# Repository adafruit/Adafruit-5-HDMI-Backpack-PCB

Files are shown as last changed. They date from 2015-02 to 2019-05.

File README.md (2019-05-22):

## Adafruit 5" HDMI Backpack PCB
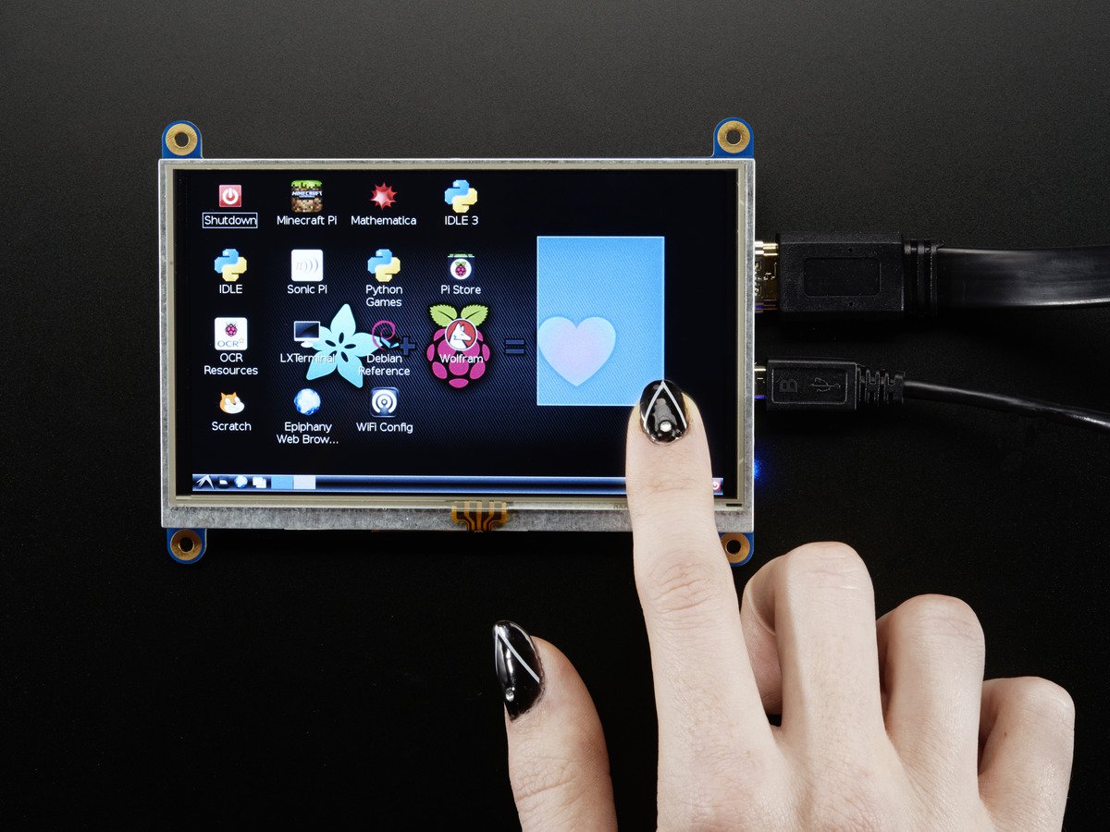
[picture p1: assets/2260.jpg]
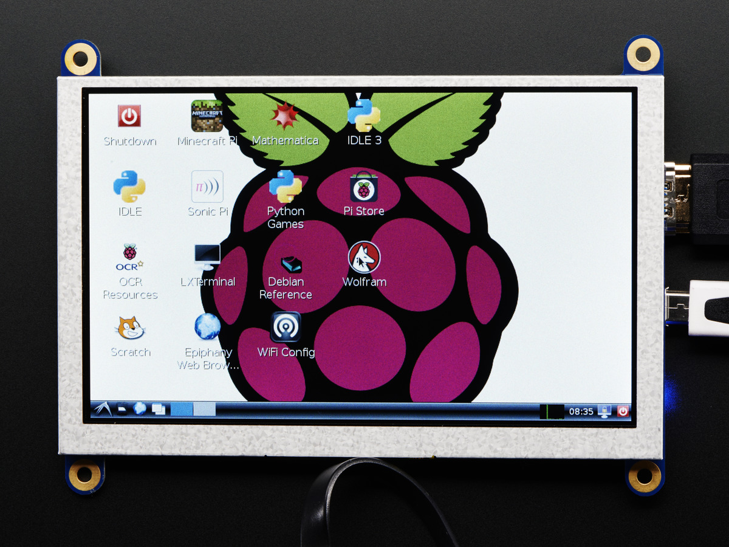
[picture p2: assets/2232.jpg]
&nbsp; <br />
Click to purchase from the Adafruit Shop:
- [HDMI 5" 800x480 Display Backpack - With Resistive Touchscreen](https://www.adafruit.com/product/2260)
- [HDMI 5" Display Backpack - Without Touch](https://www.adafruit.com/product/2232)

Its a mini panel-mountable HDMI monitor with a built-in resistive touchscreen! So small and simple, you can use this display with any computer that has HDMI output, and the shape makes it easy to attach to a case or rail. This backpack features the TFP401 for decoding video, and includes the attached display so its plug-n-play.

The TFP401 is a beefy DVI/HDMI decoder from TI. It can take unencrypted video and pipe out the raw 24-bit color pixel data - HDCP not supported! The 5" display is 800x480 resolution, which is just enough to run most software, but still small enough that it can be used in portable or embedded projects without the bulk.

This is the PCB for the Adafruit 5" TFT HDMI backpacks. The format is EagleCAD schematic and board layout

For more details, check out the product pages at
- https://www.adafruit.com/product/2260
- https://www.adafruit.com/product/2232

### License

Adafruit invests time and resources providing this open source design, please support Adafruit and open-source hardware by purchasing products from [Adafruit](https://www.adafruit.com)!

All text above must be included in any redistribution

Designed by Limor Fried/Ladyada for Adafruit Industries.
Creative Commons Attribution/Share-Alike, all text above must be included in any redistribution. 
See license.txt for additional information.Adafruit invests time and resources providing this open source design, 
please support Adafruit and open-source hardware by purchasing 
products from Adafruit!

Designed by Adafruit Industries.  
Creative Commons Attribution, Share-Alike license, check license.txt for more information
All text above must be included in any redistribution

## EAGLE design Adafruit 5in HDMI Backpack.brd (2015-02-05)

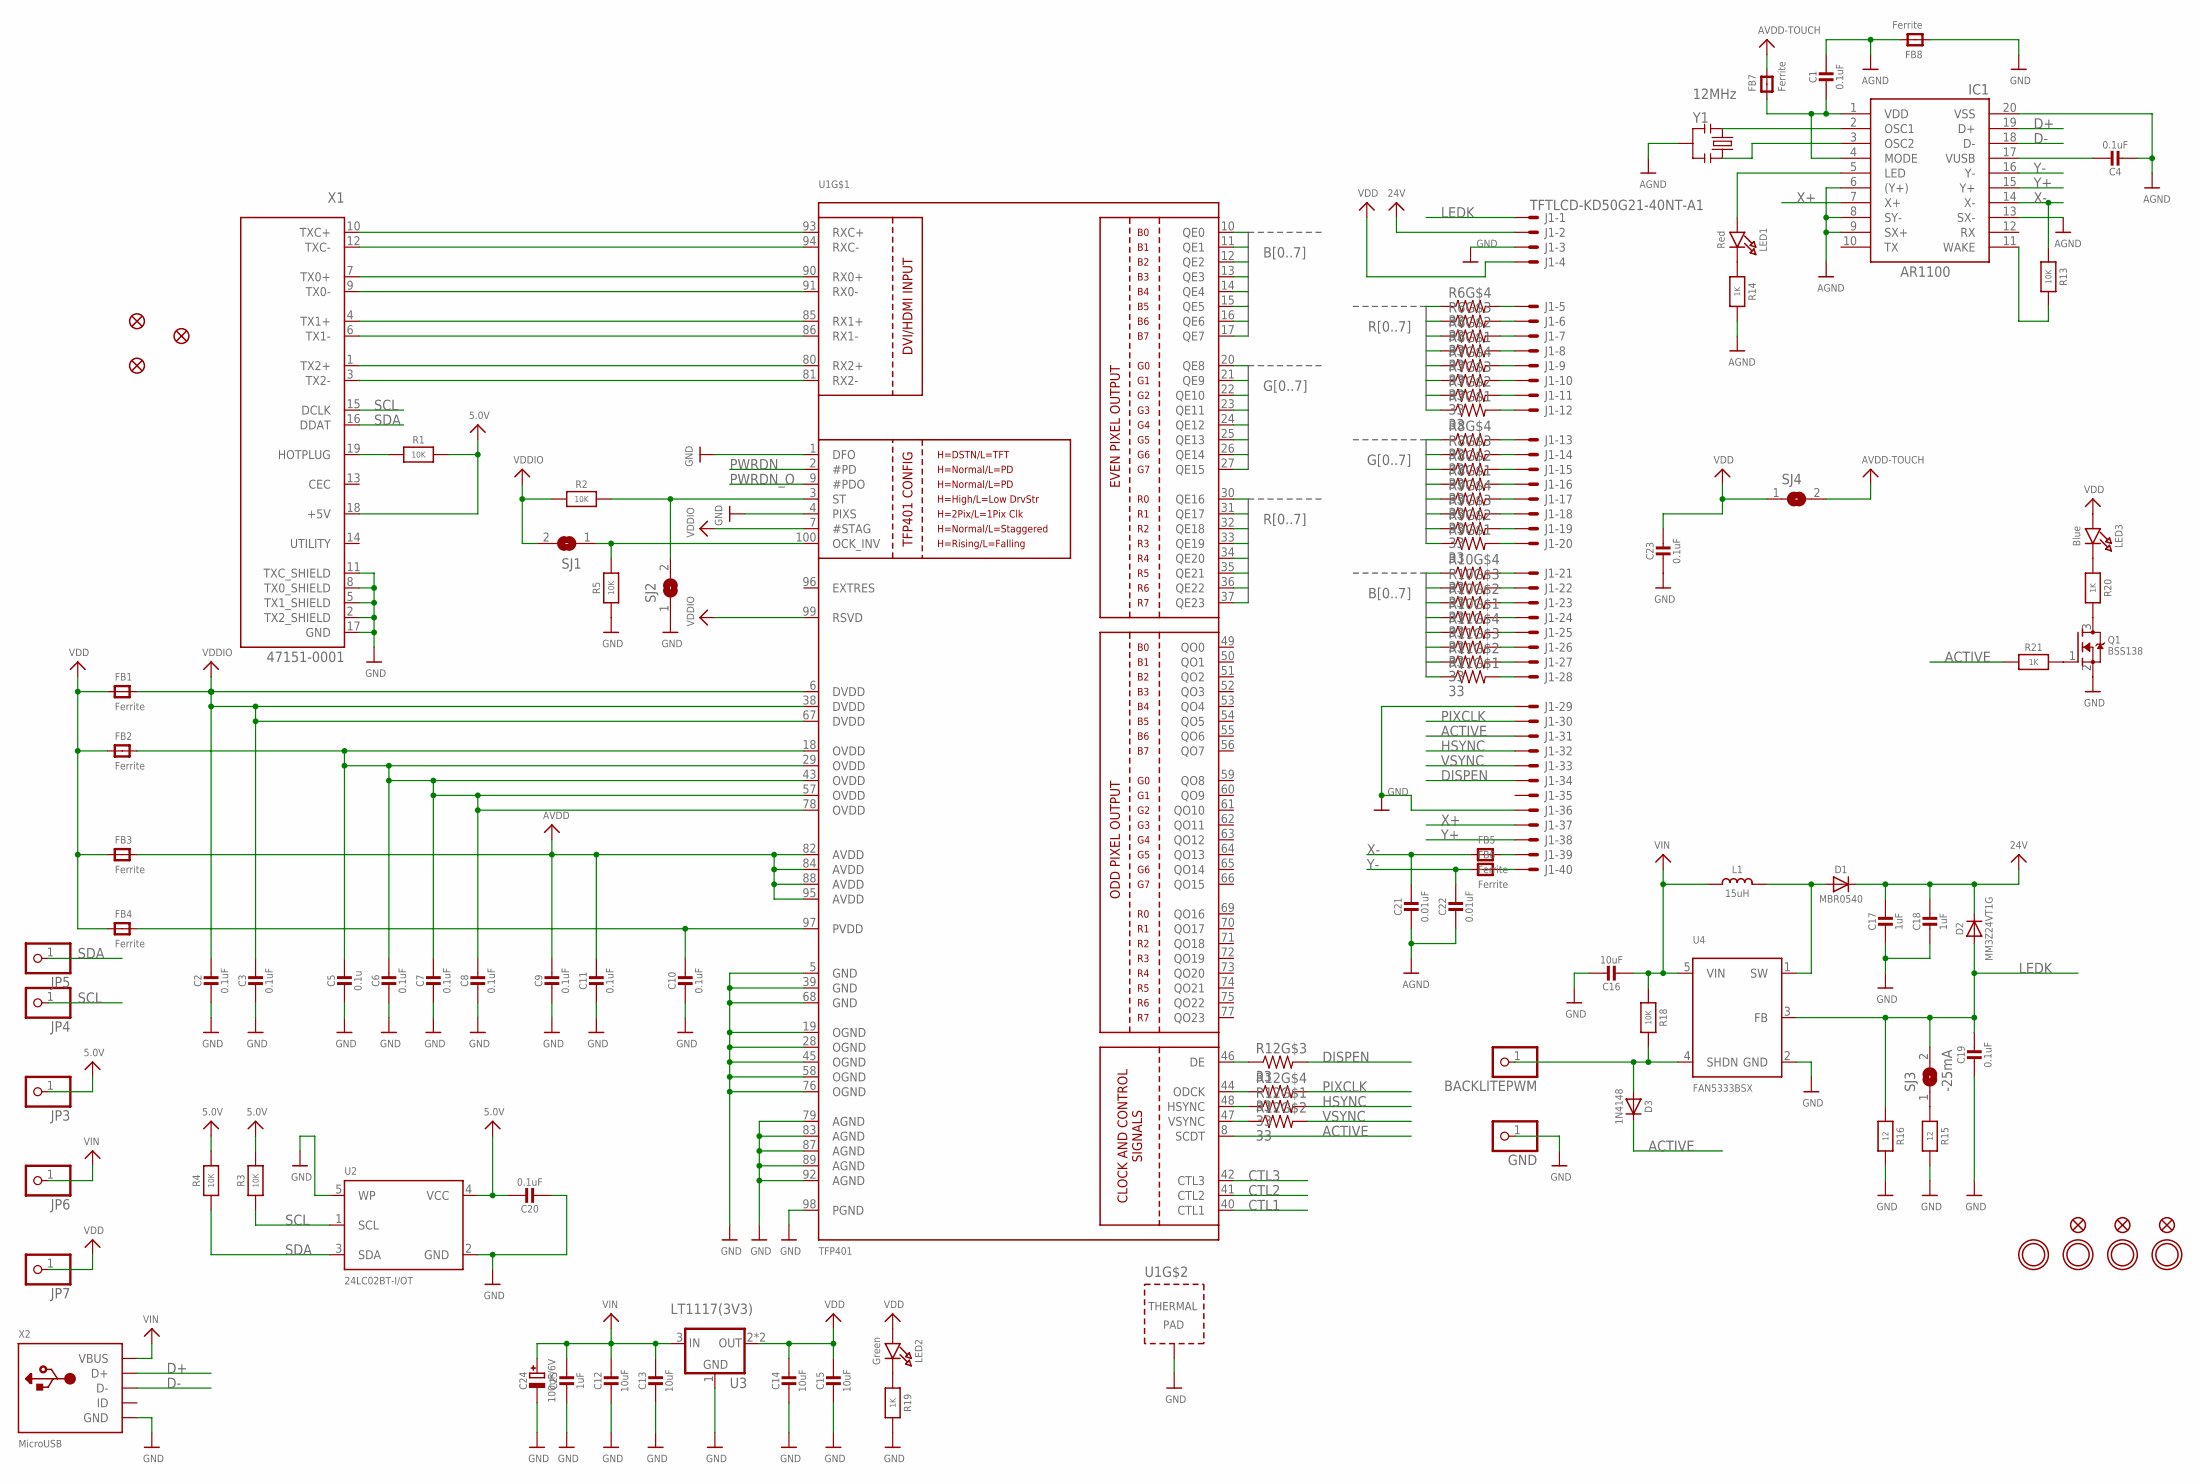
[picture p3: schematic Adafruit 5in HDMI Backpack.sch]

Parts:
BACKLITEPWM: HEADER-1X1-SMD_MASKHELD_2X2MM; 1X01_SMD_MASKHELD_2X2MM
C1, C2, C3, C7, C8, C9, C10, C11, C19, C20, C23: 0.1uF; 0805-NO
C4, C6: 0.1uF; _0805MP
C5: 0.1u; 0805-NO
C12, C13, C14, C15, C16: 10uF; 0805-NO
C17, C18, C25: 1uF; 0805-NO
C21, C22: 0.01uF; 0805-NO
C24: 100uF/6V; PANASONIC_C
D1: MBR0540; SOD-123
D2: MM3Z24VT1G; SMADIODE
D3: 1N4148; SOD-323
FB1, FB2, FB3, FB4, FB5, FB6, FB7, FB8: Ferrite; _0805MP
FID1, FID2, FID3, FID4, FID5, FID6: FIDUCIAL""; FIDUCIAL_1MM
GND: HEADER-1X1-SMD_MASKHELD_2X2MM; 1X01_SMD_MASKHELD_2X2MM
IC1: AR1100; TSSOP20-5.3MMBODY
J1: TFTLCD-KD50G21-40NT-A1
JP3, JP4, JP5, JP6, JP7: HEADER-1X1-SMD_MASKHELD_2X2MM; 1X01_SMD_MASKHELD_2X2MM
L1: 15uH; INDUCTOR_5X5MM_NR5040_NOTHERMALS
LED1: Red; CHIPLED_0805_NOOUTLINE
LED2: Green; CHIPLED_0805_NOOUTLINE
LED3: Blue; CHIPLED_0805_NOOUTLINE
Q1: BSS138; SOT23-WIDE
R1, R3, R4, R13, R18: 10K; 0805-NO
R2, R5: 10K; _0805MP
R6, R7, R8, R9, R10, R11, R12: 33; RESPACK_4X0603
R14, R19, R20, R21: 1K; 0805-NO
R15, R16: 12; 0805-NO
SJ1, SJ2: SOLDERJUMPER; SOLDERJUMPER_ARROW_NOPASTE
SJ3: -25mA; SOLDERJUMPER_CLOSEDWIRE
SJ4: SOLDERJUMPERCLOSED; SOLDERJUMPER_CLOSEDWIRE
U1: TFP401; S-PQFP-G100
U2: 24LC02BT-I/OT; SOT23-5
U3: LT1117(3V3); SOT223-R
U4: FAN5333BSX; SOT23-5
U$31, U$32, U$33, U$34: MOUNTINGHOLE3.0; MOUNTINGHOLE_3.0_PLATED
X1: 47151-0001; HDMI_MOLEX_47151-0001_DIMLAYER
X2: MicroUSB; 4UCONN_20329
Y1: 12MHz; RESONATOR-SMD

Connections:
5.0V: C20.1, JP3.1, R1.2, R3.2, R4.2, U2.4 (VCC), X1.18 (+5V)
24V: C17.1, C18.1, D1.C, D2.C, J1.2 (MS)
ACTIVE: D3.C, J1.31 (MS), R21.1, U1.8 (SCDT)
AGND: C1.1, C4.2, C21.2, C22.2, FB8.2, IC1.6 ((Y+)), IC1.8 (SY-), IC1.9 (SX+), IC1.13 (SX-), IC1.20 (VSS), R14.2, Y1.2
ASD: R12.3 (1), U1.46 (DE)
AVDD: C9.1, C11.1, FB3.2, U1.82 (AVDD), U1.84 (AVDD), U1.88 (AVDD), U1.95 (AVDD)
AVDD2: FB7.2, SJ4.2
B0: R10.4 (1), U1.10 (QE0)
B1: R10.3 (1), U1.11 (QE1)
B2: R10.2 (1), U1.12 (QE2)
B3: R10.1, U1.13 (QE3)
B4: R11.4 (1), U1.14 (QE4)
B5: R11.3 (1), U1.15 (QE5)
B6: R11.2 (1), U1.16 (QE6)
B7: R11.1, U1.17 (QE7)
CTL1: U1.40 (CTL1)
CTL2: U1.41 (CTL2)
CTL3: U1.42 (CTL3)
CVB: R12.2 (1), U1.47 (VSYNC)
D+: IC1.19 (D+), X2.D+
D-: IC1.18 (D-), X2.D-
DISPEN: J1.34 (MS), R12.6 (2)
G0: R8.4 (1), U1.20 (QE8)
G1: R8.3 (1), U1.21 (QE9)
G2: R8.2 (1), U1.22 (QE10)
G3: R8.1, U1.23 (QE11)
G4: R9.4 (1), U1.24 (QE12)
G5: R9.3 (1), U1.25 (QE13)
G6: R9.2 (1), U1.26 (QE14)
G7: R9.1, U1.27 (QE15)
GND: C2.2, C3.2, C5.2, C6.2, C7.2, C8.2, C9.2, C10.2, C11.2, C12.2, C13.2, C14.2, C15.2, C16.1, C17.2, C18.2, C19.2, C20.2, C23.2, C24.-, C25.2, FB8.1, GND.1, J1.3 (MS), J1.29 (MS), J1.36 (MS), Q1.2 (S), R5.1, R15.2, R16.2, R19.2, SJ2.1, U1.1 (DFO), U1.4 (PIXS), U1.5 (GND), U1.19 (OGND), U1.28 (OGND), U1.39 (GND), U1.45 (OGND), U1.58 (OGND), U1.68 (GND), U1.76 (OGND), U1.79 (AGND), U1.83 (AGND), U1.87 (AGND), U1.89 (AGND), U1.92 (AGND), U1.98 (PGND), U1.P$1 (TP), U1.P$2 (TP), U1.P$3 (TP), U1.P$4 (TP), U1.P$5 (TP), U1.P$6 (TP), U1.P$7 (TP), U1.P$8 (TP), U1.P$9 (TP), U1.P$10 (TP), U1.P$11 (TP), U1.P$12 (TP), U1.P$13 (TP), U1.P$14 (TP), U1.P$15 (TP), U1.P$16 (TP), U1.THERMAL (TP), U2.2 (GND), U2.5 (WP), U3.1 (GND), U4.2 (GND), X1.2 (TX2_SHIELD), X1.5 (TX1_SHIELD), X1.8 (TX0_SHIELD), X1.11 (TXC_SHIELD), X1.17 (GND), X1.P$1 (GND), X1.P$2 (GND), X1.P$3 (GND), X1.P$4 (GND), X2.BASE@1 (GND), X2.BASE@2 (GND), X2.GND, X2.SPRT@1 (GND), X2.SPRT@2 (GND), X2.SPRT@3 (GND), X2.SPRT@4 (GND)
HSYNC: J1.32 (MS), R12.8 (2)
LEDK: C19.1, D2.A, J1.1 (MSV), R16.1, SJ3.2, U4.3 (FB)
unnamed: U1.93 (RXC+), X1.10 (TXC+)
unnamed: U1.94 (RXC-), X1.12 (TXC-)
unnamed: U1.90 (RX0+), X1.7 (TX0+)
unnamed: U1.91 (RX0-), X1.9 (TX0-)
unnamed: U1.85 (RX1+), X1.4 (TX1+)
unnamed: U1.86 (RX1-), X1.6 (TX1-)
unnamed: U1.80 (RX2+), X1.1 (TX2+)
unnamed: U1.81 (RX2-), X1.3 (TX2-)
unnamed: R1.1, X1.19 (HOTPLUG)
unnamed: IC1.2 (OSC1), Y1.1
unnamed: IC1.3 (OSC2), Y1.3
unnamed: C4.1, IC1.17 (VUSB)
unnamed: LED2.C, R19.1
unnamed: J1.5 (MS), R6.5 (2)
unnamed: J1.6 (MS), R6.6 (2)
unnamed: J1.7 (MS), R6.7 (2)
unnamed: J1.8 (MS), R6.8 (2)
unnamed: J1.9 (MS), R7.5 (2)
unnamed: J1.10 (MS), R7.6 (2)
unnamed: J1.11 (MS), R7.7 (2)
unnamed: J1.12 (MS), R7.8 (2)
unnamed: J1.13 (MS), R8.5 (2)
unnamed: J1.14 (MS), R8.6 (2)
unnamed: J1.15 (MS), R8.7 (2)
unnamed: J1.16 (MS), R8.8 (2)
unnamed: J1.17 (MS), R9.5 (2)
unnamed: J1.18 (MS), R9.6 (2)
unnamed: J1.19 (MS), R9.7 (2)
unnamed: J1.20 (MS), R9.8 (2)
unnamed: J1.21 (MS), R10.5 (2)
unnamed: J1.22 (MS), R10.6 (2)
unnamed: J1.23 (MS), R10.7 (2)
unnamed: J1.24 (MS), R10.8 (2)
unnamed: J1.25 (MS), R11.5 (2)
unnamed: J1.26 (MS), R11.6 (2)
unnamed: J1.27 (MS), R11.7 (2)
unnamed: C10.1, FB4.2, U1.97 (PVDD)
unnamed: J1.28 (MS), R11.8 (2)
unnamed: IC1.11 (WAKE), R13.2
unnamed: LED1.C, R14.1
unnamed: C5.1, C6.1, C7.1, C8.1, FB2.2, U1.18 (OVDD), U1.29 (OVDD), U1.43 (OVDD), U1.57 (OVDD), U1.78 (OVDD)
unnamed: IC1.5 (LED), LED1.A
unnamed: LED3.C, R20.1
unnamed: Q1.3 (D), R20.2
unnamed: D1.A, L1.P$2 (2), U4.1 (SW)
unnamed: Q1.1 (G), R21.2
unnamed: R15.1, SJ3.1
unnamed: BACKLITEPWM.1, D3.A, R18.2, U4.4 (SHDN)
unnamed: FB5.2, J1.39 (MS)
unnamed: FB6.2, J1.40 (MS)
unnamed: C1.2, FB7.1, IC1.1 (VDD), IC1.4 (MODE)
OCK_INV: R5.2, SJ1.1, U1.100 (OCK_INV)
PIXCLK: J1.30 (MS), R12.5 (2)
PWRDN: U1.2 (#PD)
PWRDN_O: U1.9 (#PDO)
R0: R6.4 (1), U1.30 (QE16)
R1: R6.3 (1), U1.31 (QE17)
R2: R6.2 (1), U1.32 (QE18)
R3: R6.1, U1.33 (QE19)
R4: R7.4 (1), U1.34 (QE20)
R5: R7.3 (1), U1.35 (QE21)
R6: R7.2 (1), U1.36 (QE22)
R7: R7.1, U1.37 (QE23)
SCL: JP4.1, R3.1, U2.1 (SCL), X1.15 (DCLK)
SDA: JP5.1, R4.1, U2.3 (SDA), X1.16 (DDAT)
ST: R2.2, SJ2.2, U1.3 (ST)
VDD: C14.1, C15.1, C23.1, FB1.1, FB2.1, FB3.1, FB4.1, J1.4 (MS), JP7.1, LED2.A, LED3.A, SJ4.1, U3.2 (OUT), U3.4 (OUT)
VDDIO: C2.1, C3.1, FB1.2, R2.1, SJ1.2, U1.6 (DVDD), U1.7 (#STAG), U1.38 (DVDD), U1.67 (DVDD), U1.99 (RSVD)
VIN: C12.1, C13.1, C16.2, C24.+, C25.1, JP6.1, L1.P$1 (1), R18.1, U3.3 (IN), U4.5 (VIN), X2.VBUS
VSYNC: J1.33 (MS), R12.7 (2)
X+: IC1.7 (X+), J1.37 (MS)
X-: C21.1, FB5.1, IC1.14 (X-), R13.1
XCV: R12.1, U1.48 (HSYNC)
Y+: IC1.15 (Y+), J1.38 (MS)
Y-: C22.1, FB6.1, IC1.16 (Y-)
ZXC: R12.4 (1), U1.44 (ODCK)

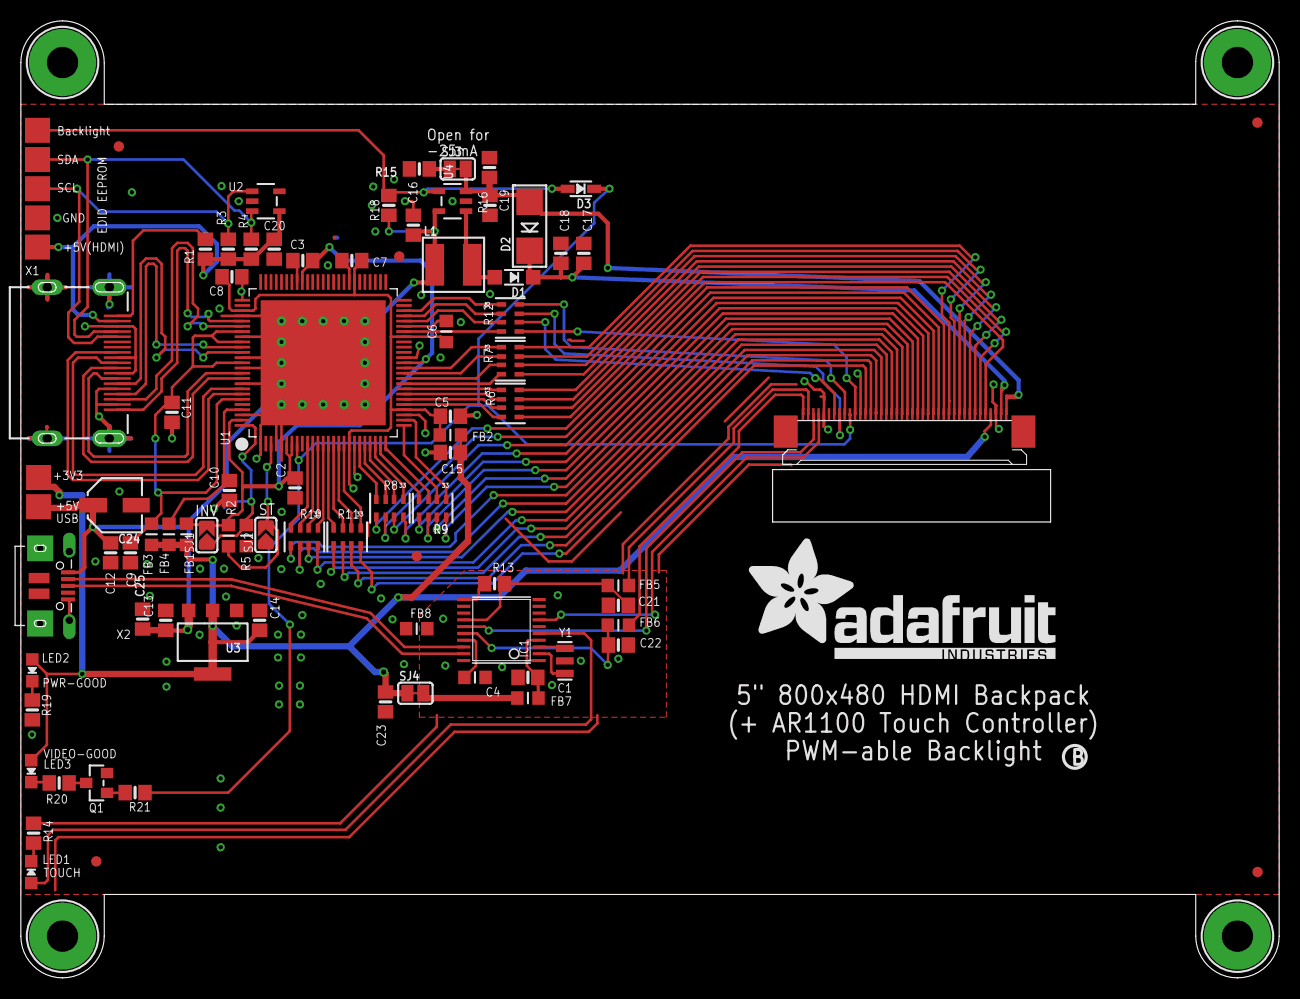
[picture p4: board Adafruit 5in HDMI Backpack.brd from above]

Board: 2 copper layers, 120.7 x 91.8 mm, 93 parts (1 on the bottom side), 104 nets.

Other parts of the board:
U$75: ADAFRUIT_TEXT_30MM
U$76: PCBFEAT-REV-056

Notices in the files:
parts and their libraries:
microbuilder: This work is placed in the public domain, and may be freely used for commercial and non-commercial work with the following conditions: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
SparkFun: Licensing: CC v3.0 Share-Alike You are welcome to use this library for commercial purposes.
